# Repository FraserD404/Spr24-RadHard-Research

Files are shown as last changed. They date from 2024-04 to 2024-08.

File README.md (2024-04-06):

# Spr24 RadHard Research

## Overview:
EEPROM Control Code for Research

This code initializes EEPROMs on a PCB in select banks and then continuously dumps the data to see if there has been a bit flip.
This code is designed to run on a Raspberry Pi 4 with wiringPi library on a 1 MHz I2C bus.

## Known Issues:
- This is not memory safe as there is no code to free the alloc'd data structures. Only ~24 MB of garbage, however. I plan on fixing this soon.
- This code is prone to segmentation faults if any of the pins are disconnected. I don't know the fix for this.
- A full array dump takes approximately 2 minutes if the 512k dump is done in one pass. This is a limitation of the I2C bus. 
- This code could probably be more efficient time & space complexity-wise. I'll probably optimize this at some point.
- There is no tracking individual bit flips. This would be a reasonably simple implementation but time limits me. I do plan on implementing this.

## Files
Control File: radpicode.c
Test Files: filewriting.c , maybe.c

To compile on a Raspberry Pi: **gcc -o rad radpicode.c -l wiringPi**

Memory Usage: ~25 MB allocated total for 16 EEPROMs

CSV Size: ~1.3 KB over 5 minutes

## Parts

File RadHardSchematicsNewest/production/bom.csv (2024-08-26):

Designator | Footprint | Quantity | Value | LCSC Part #
A2 | Arduino_UNO_R3 | 1 | Arduino_UNO_R3
R10, R11, R12, R13, R14, R15, R4, R5, R6, R9 | 0603 | 10 | 10k
U1, U2 | TSSOP-16_4.4x5mm_P0.65mm | 2 | 74CBTLV3257
U10, U9 | TSSOP-8_4.4x3mm_P0.65mm | 2 | CAT24C 512XHM
U11, U14 | SOIC-8_3.9x4.9mm_P1.27mm | 2 | AT24CS01-SSHM
U12, U15 | SOIC-8_3.9x4.9mm_P1.27mm | 2 | AT24CS32-SSHM
U13, U16 | SOIC-8_3.9x4.9mm_P1.27mm | 2 | CAT24C128 SSHM
U17, U20 | TSSOP-8_4.4x3mm_P0.65mm | 2 | AT24CS01-XHM
U18, U21 | TSSOP-8_4.4x3mm_P0.65mm | 2 | AT24CS32-XHM
U19, U22 | TSSOP-8_4.4x3mm_P0.65mm | 2 | CAT24C128 XHM
U3, U4 | SOIC-8_3.9x4.9mm_P1.27mm | 2 | AT24CS04-SSHM
U5, U6 | TSSOP-8_4.4x3mm_P0.65mm | 2 | AT24CS04-XHM
U7, U8 | SOIC-8_3.9x4.9mm_P1.27mm | 2 | CAT24C 512

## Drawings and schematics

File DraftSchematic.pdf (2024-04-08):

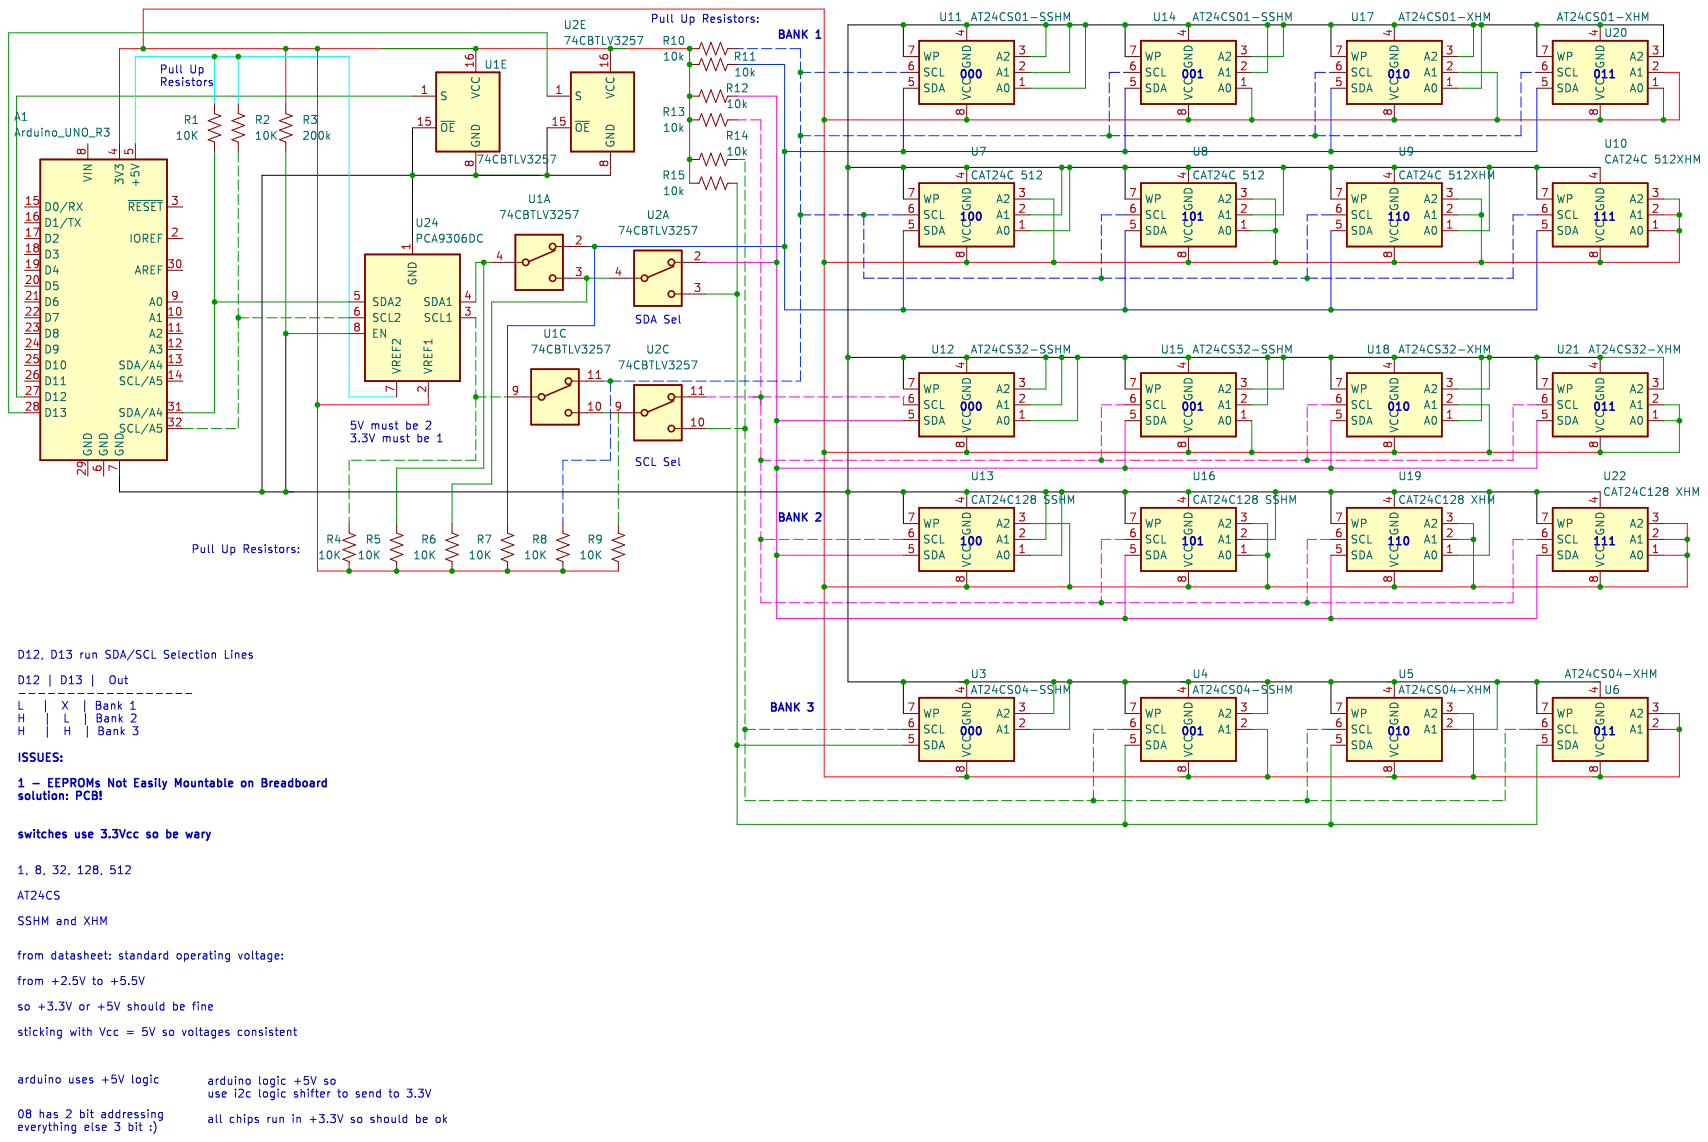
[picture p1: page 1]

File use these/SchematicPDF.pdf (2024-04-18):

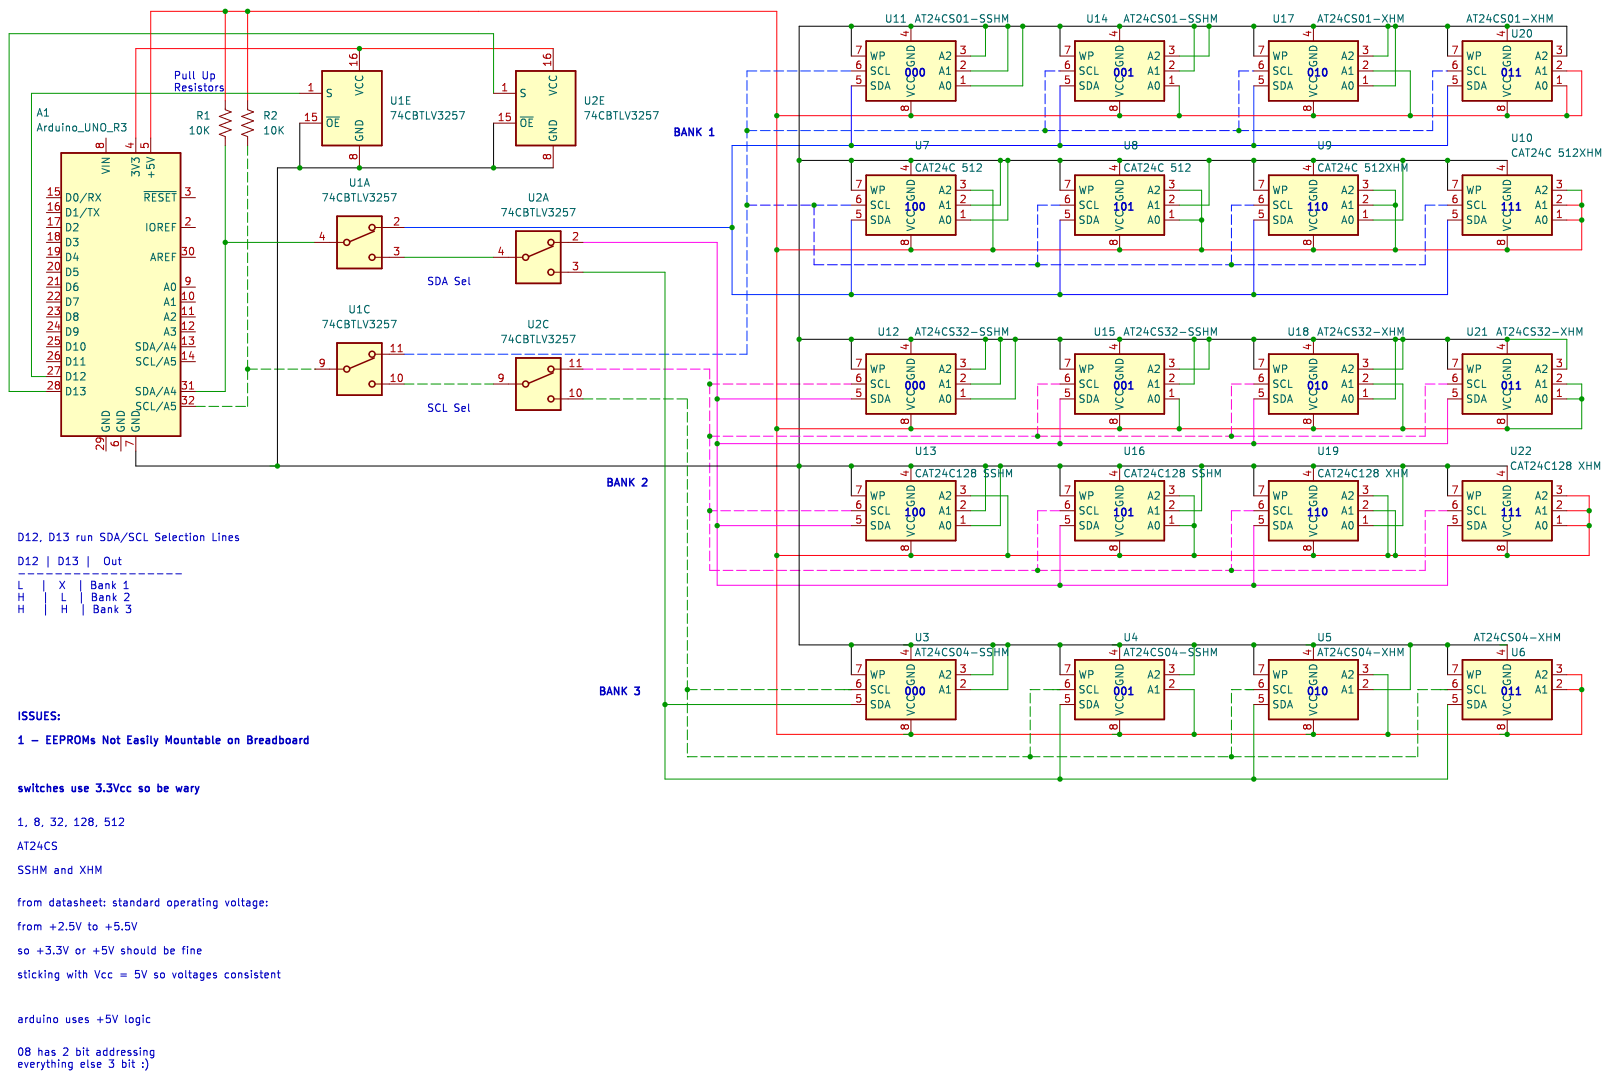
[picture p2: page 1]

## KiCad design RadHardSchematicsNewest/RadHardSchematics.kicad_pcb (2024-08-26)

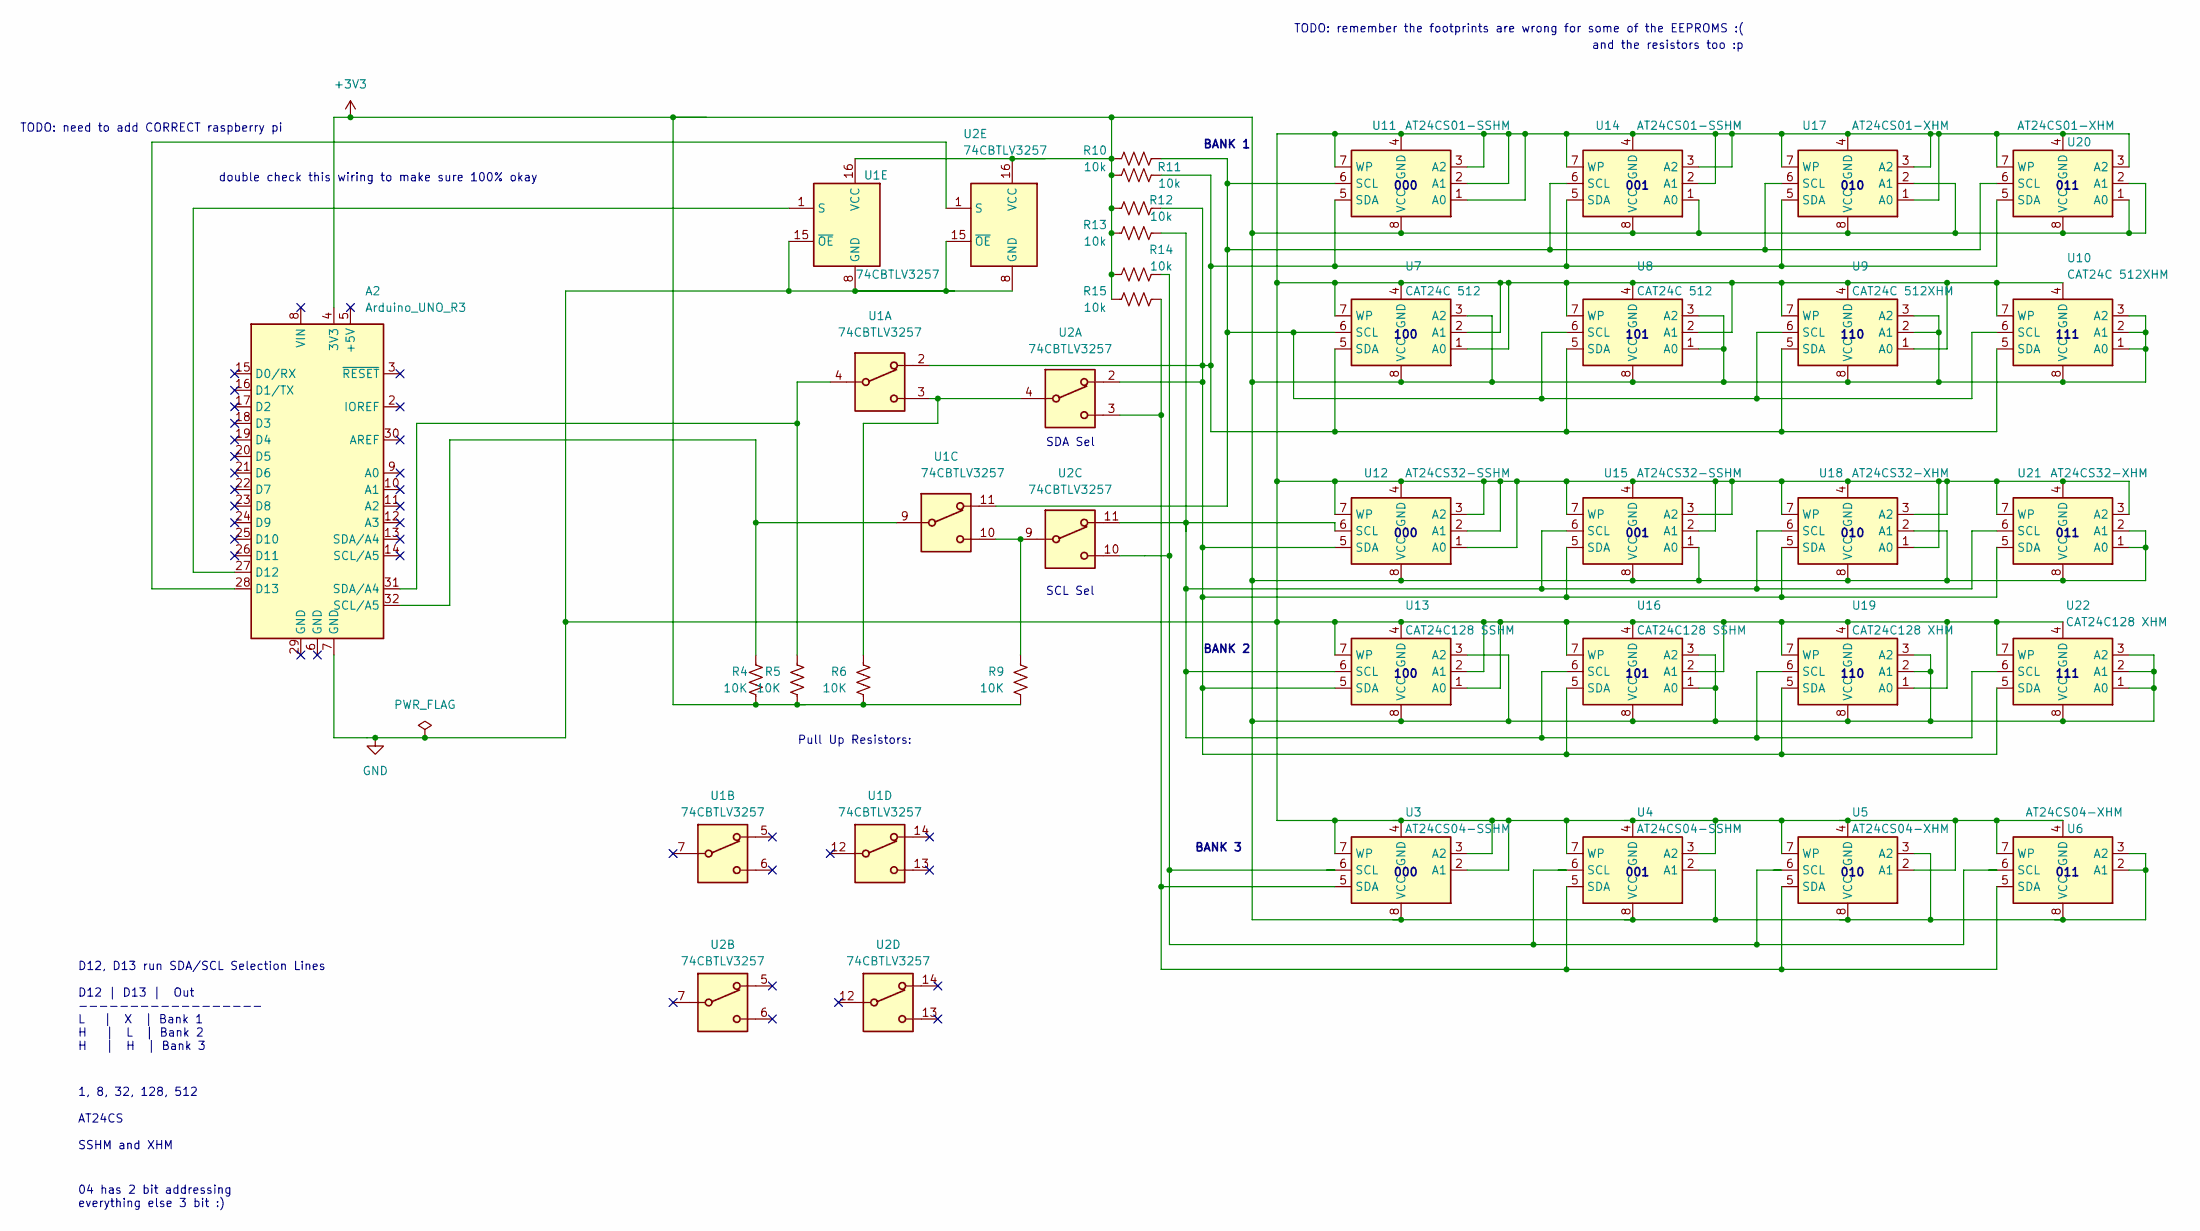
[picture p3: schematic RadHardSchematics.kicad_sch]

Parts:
A2: Arduino_UNO_R3
R4, R5, R6, R9: 10K; R_0603_1608Metric
R10, R11, R12, R13, R14, R15: 10k; R_0603_1608Metric
U1, U2: 74CBTLV3257; TSSOP-16_4.4x5mm_P0.65mm
U3, U4: AT24CS04-SSHM; SOIC-8_3.9x4.9mm_P1.27mm
U5, U6: AT24CS04-XHM; TSSOP-8_4.4x3mm_P0.65mm
U7, U8: CAT24C 512; SOIC-8_3.9x4.9mm_P1.27mm
U9, U10: CAT24C 512XHM; TSSOP-8_4.4x3mm_P0.65mm
U11, U14: AT24CS01-SSHM; SOIC-8_3.9x4.9mm_P1.27mm
U12, U15: AT24CS32-SSHM; SOIC-8_3.9x4.9mm_P1.27mm
U13, U16: CAT24C128 SSHM; SOIC-8_3.9x4.9mm_P1.27mm
U17, U20: AT24CS01-XHM; TSSOP-8_4.4x3mm_P0.65mm
U18, U21: AT24CS32-XHM; TSSOP-8_4.4x3mm_P0.65mm
U19, U22: CAT24C128 XHM; TSSOP-8_4.4x3mm_P0.65mm

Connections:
+3V3: A2.4 (3V3), R4.1, R5.1, R6.1, R9.1, R10.1, R11.1, R12.1, R13.1, R14.1, R15.1, U1.16 (VCC), U2.16 (VCC), U3.8 (VCC), U4.2 (A1), U4.8 (VCC), U5.3 (A2), U5.8 (VCC), U6.2 (A1), U6.3 (A2), U6.8 (VCC), U7.3 (A2), U7.8 (VCC), U8.1 (A0), U8.3 (A2), U8.8 (VCC), U9.2 (A1), U9.3 (A2), U9.8 (VCC), U10.1 (A0), U10.2 (A1), U10.3 (A2), U10.8 (VCC), U11.8 (VCC), U12.8 (VCC), U13.3 (A2), U13.8 (VCC), U14.1 (A0), U14.8 (VCC), U15.1 (A0), U15.8 (VCC), U16.1 (A0), U16.3 (A2), U16.8 (VCC), U17.2 (A1), U17.8 (VCC), U18.2 (A1), U18.8 (VCC), U19.2 (A1), U19.3 (A2), U19.8 (VCC), U20.1 (A0), U20.2 (A1), U20.8 (VCC), U21.1 (A0), U21.2 (A1), U21.8 (VCC), U22.1 (A0), U22.2 (A1), U22.3 (A2), U22.8 (VCC)
GND: A2.7 (GND), U1.8 (GND), U1.15 (~OE), U2.8 (GND), U2.15 (~OE), U3.2 (A1), U3.3 (A2), U3.4 (GND), U3.7 (WP), U4.3 (A2), U4.4 (GND), U4.7 (WP), U5.2 (A1), U5.4 (GND), U5.7 (WP), U6.4 (GND), U6.7 (WP), U7.1 (A0), U7.2 (A1), U7.4 (GND), U7.7 (WP), U8.2 (A1), U8.4 (GND), U8.7 (WP), U9.1 (A0), U9.4 (GND), U9.7 (WP), U10.4 (GND), U10.7 (WP), U11.1 (A0), U11.2 (A1), U11.3 (A2), U11.4 (GND), U11.7 (WP), U12.1 (A0), U12.2 (A1), U12.3 (A2), U12.4 (GND), U12.7 (WP), U13.1 (A0), U13.2 (A1), U13.4 (GND), U13.7 (WP), U14.2 (A1), U14.3 (A2), U14.4 (GND), U14.7 (WP), U15.2 (A1), U15.3 (A2), U15.4 (GND), U15.7 (WP), U16.2 (A1), U16.4 (GND), U16.7 (WP), U17.1 (A0), U17.3 (A2), U17.4 (GND), U17.7 (WP), U18.1 (A0), U18.3 (A2), U18.4 (GND), U18.7 (WP), U19.1 (A0), U19.4 (GND), U19.7 (WP), U20.3 (A2), U20.4 (GND), U20.7 (WP), U21.3 (A2), U21.4 (GND), U21.7 (WP), U22.4 (GND), U22.7 (WP)
unnamed: A2.27 (D12), U1.1 (S)
unnamed: A2.28 (D13), U2.1 (S)
unnamed: A2.32 (SCL/A5), R4.2, U1.9
unnamed: A2.31 (SDA/A4), R5.2, U1.4
unnamed: R6.2, U1.3, U2.4
unnamed: R9.2, U1.10, U2.9
unnamed: R14.2, U2.10, U3.6 (SCL), U4.6 (SCL), U5.6 (SCL), U6.6 (SCL)
unnamed: R15.2, U2.3, U3.5 (SDA), U4.5 (SDA), U5.5 (SDA), U6.5 (SDA)
unnamed: R10.2, U1.11, U7.6 (SCL), U8.6 (SCL), U9.6 (SCL), U10.6 (SCL), U11.6 (SCL), U14.6 (SCL), U17.6 (SCL), U20.6 (SCL)
unnamed: R11.2, R12.2, U1.2, U2.2, U7.5 (SDA), U8.5 (SDA), U9.5 (SDA), U10.5 (SDA), U11.5 (SDA), U12.5 (SDA), U13.5 (SDA), U14.5 (SDA), U15.5 (SDA), U16.5 (SDA), U17.5 (SDA), U18.5 (SDA), U19.5 (SDA), U20.5 (SDA), U21.5 (SDA), U22.5 (SDA)
unnamed: R13.2, U2.11, U12.6 (SCL), U13.6 (SCL), U15.6 (SCL), U16.6 (SCL), U18.6 (SCL), U19.6 (SCL), U21.6 (SCL), U22.6 (SCL)

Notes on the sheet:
SCL Sel
BANK 2
011
010
double check this wiring to make sure 100% okay
D12, D13 run SDA/SCL Selection Lines D12 | D13 | Out ------------------ L | X | Bank 1 H | L | Bank 2 H | H | Bank 3
111
001
110
Pull Up Resistors:
101
1, 8, 32, 128, 512 AT24CS SSHM and XHM
TODO: need to add CORRECT raspberry pi
04 has 2 bit addressing everything else 3 bit :)
100
BANK 1
000
TODO: remember the footprints are wrong for some of the EEPROMS :(
SDA Sel
and the resistors too :p
BANK 3

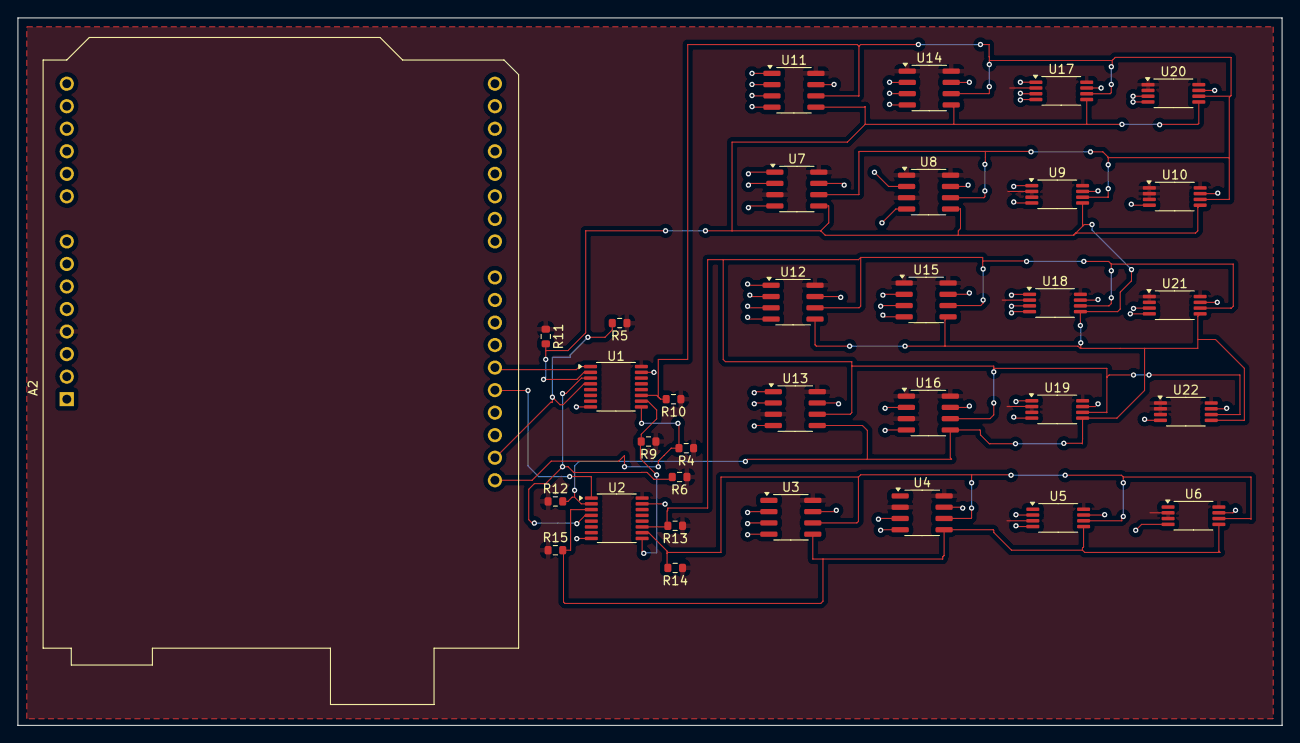
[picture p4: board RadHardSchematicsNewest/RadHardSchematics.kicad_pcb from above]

Board: 2 copper layers, 142.5 x 79.8 mm, 33 parts (0 on the bottom side), 13 nets.

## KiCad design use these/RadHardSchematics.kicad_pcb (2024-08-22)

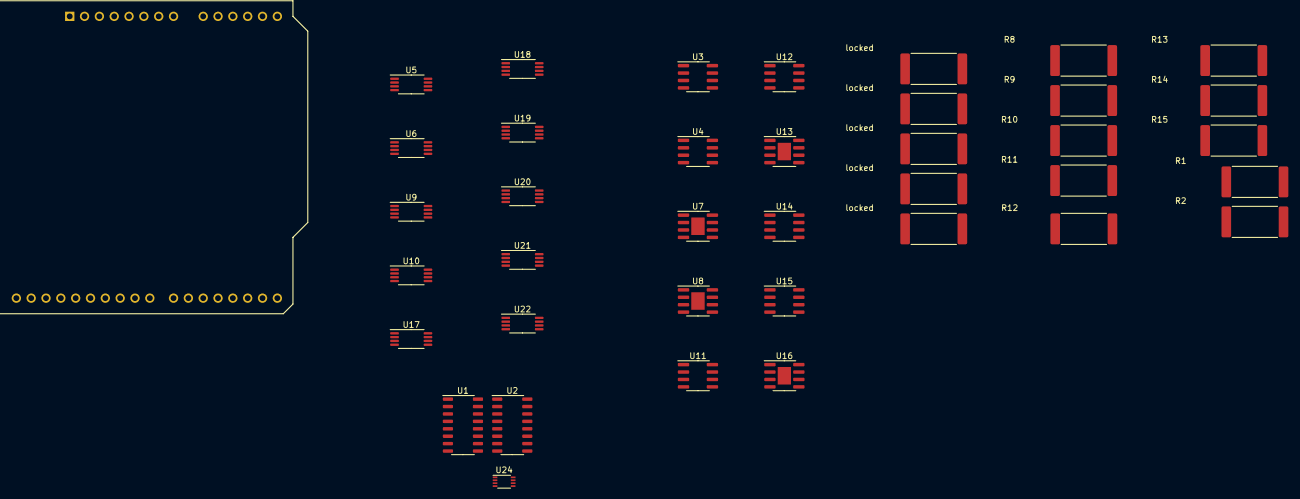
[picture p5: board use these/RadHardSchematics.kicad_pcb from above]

Board: 2 copper layers, 39 parts (0 on the bottom side), 16 nets, no tracks yet.

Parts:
A1: Arduino_UNO_R3
R1, R2, R8, R9: 10K; R_4020_10251Metric_Pad1.65x5.30mm_HandSolder
R10, R11, R12, R13, R14, R15: 10k; R_4020_10251Metric_Pad1.65x5.30mm_HandSolder
U1, U2: 74CBTLV3257; SO-16_3.9x9.9mm_P1.27mm
U3, U4: AT24CS04-SSHM; SOIC-8_3.9x4.9mm_P1.27mm
U5, U6: AT24CS04-XHM; TSSOP-8_4.4x3mm_P0.65mm
U7, U8: CAT24C 512; SOIC-8-1EP_3.9x4.9mm_P1.27mm_EP2.29x3mm
U9, U10: CAT24C 512XHM; TSSOP-8_4.4x3mm_P0.65mm
U11, U14: AT24CS01-SSHM; SOIC-8_3.9x4.9mm_P1.27mm
U12, U15: AT24CS32-SSHM; SOIC-8_3.9x4.9mm_P1.27mm
U13, U16: CAT24C128 SSHM; SOIC-8-1EP_3.9x4.9mm_P1.27mm_EP2.29x3mm
U17, U20: AT24CS01-XHM; TSSOP-8_4.4x3mm_P0.65mm
U18, U21: AT24CS32-XHM; TSSOP-8_4.4x3mm_P0.65mm
U19, U22: CAT24C128 XHM; TSSOP-8_4.4x3mm_P0.65mm
U24: PCA9306DC; VSSOP-8_2.3x2mm_P0.5mm
locked: 10K; R_4020_10251Metric_Pad1.65x5.30mm_HandSolder
locked#2, locked#4, locked#5: 10K; R_4020_10251Metric_Pad1.65x5.30mm_HandSolder
locked#3: 200k; R_4020_10251Metric_Pad1.65x5.30mm_HandSolder

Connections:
unnamed: A1.4 (3V3), R1.2, R2.1, R8.1, R9.1, R10.1, R11.1, R12.1, R13.1, R14.1, R15.1, U1.16 (VCC), U2.16 (VCC), U3.8 (VCC), U4.2 (A1), U4.8 (VCC), U5.3 (A2), U5.8 (VCC), U6.2 (A1), U6.3 (A2), U6.8 (VCC), U7.3 (A2), U7.8 (VCC), U8.1 (A0), U8.3 (A2), U8.8 (VCC), U9.2 (A1), U9.3 (A2), U9.8 (VCC), U10.1 (A0), U10.2 (A1), U10.3 (A2), U10.8 (VCC), U11.8 (VCC), U12.8 (VCC), U13.3 (A2), U13.8 (VCC), U14.1 (A0), U14.8 (VCC), U15.1 (A0), U15.8 (VCC), U16.1 (A0), U16.3 (A2), U16.8 (VCC), U17.2 (A1), U17.8 (VCC), U18.2 (A1), U18.8 (VCC), U19.2 (A1), U19.3 (A2), U19.8 (VCC), U20.1 (A0), U20.2 (A1), U20.8 (VCC), U21.1 (A0), U21.2 (A1), U21.8 (VCC), U22.1 (A0), U22.2 (A1), U22.3 (A2), U22.8 (VCC), U24.2 (VREF1), locked.1, locked#2.1, locked#3.1, locked#4.1, locked#5.1
unnamed: A1.5 (+5V), U24.7 (VREF2)
unnamed: A1.27 (D12), U1.1 (S)
unnamed: A1.28 (D13), U2.1 (S)
unnamed: U1.3, U2.4, locked.2
unnamed: R14.2, U2.10, U3.6 (SCL), U4.6 (SCL), U5.6 (SCL), U6.6 (SCL)
unnamed: R15.2, U2.3, U3.5 (SDA), U4.5 (SDA), U5.5 (SDA), U6.5 (SDA)
unnamed: A1.7 (GND), U1.8 (GND), U1.15 (~OE), U2.8 (GND), U2.15 (~OE), U3.2 (A1), U3.3 (A2), U3.4 (GND), U3.7 (WP), U4.3 (A2), U4.4 (GND), U4.7 (WP), U5.2 (A1), U5.4 (GND), U5.7 (WP), U6.4 (GND), U6.7 (WP), U7.1 (A0), U7.2 (A1), U7.4 (GND), U7.7 (WP), U8.2 (A1), U8.4 (GND), U8.7 (WP), U9.1 (A0), U9.4 (GND), U9.7 (WP), U10.4 (GND), U10.7 (WP), U11.1 (A0), U11.2 (A1), U11.3 (A2), U11.4 (GND), U11.7 (WP), U12.1 (A0), U12.2 (A1), U12.3 (A2), U12.4 (GND), U12.7 (WP), U13.1 (A0), U13.2 (A1), U13.4 (GND), U13.7 (WP), U14.2 (A1), U14.3 (A2), U14.4 (GND), U14.7 (WP), U15.2 (A1), U15.3 (A2), U15.4 (GND), U15.7 (WP), U16.2 (A1), U16.4 (GND), U16.7 (WP), U17.1 (A0), U17.3 (A2), U17.4 (GND), U17.7 (WP), U18.1 (A0), U18.3 (A2), U18.4 (GND), U18.7 (WP), U19.1 (A0), U19.4 (GND), U19.7 (WP), U20.3 (A2), U20.4 (GND), U20.7 (WP), U21.3 (A2), U21.4 (GND), U21.7 (WP), U22.4 (GND), U22.7 (WP), U24.1 (GND), U24.8 (EN), locked#3.2
unnamed: R8.2, R10.2, U1.10, U1.11, U2.9, U7.6 (SCL), U8.6 (SCL), U9.6 (SCL), U10.6 (SCL), U11.6 (SCL), U14.6 (SCL), U17.6 (SCL), U20.6 (SCL)
unnamed: R11.2, U1.2, U7.5 (SDA), U8.5 (SDA), U9.5 (SDA), U10.5 (SDA), U11.5 (SDA), U14.5 (SDA), U17.5 (SDA), U20.5 (SDA), locked#5.2
unnamed: R13.2, U2.11, U12.6 (SCL), U13.6 (SCL), U15.6 (SCL), U16.6 (SCL), U18.6 (SCL), U19.6 (SCL), U21.6 (SCL), U22.6 (SCL)
unnamed: R12.2, U2.2, U12.5 (SDA), U13.5 (SDA), U15.5 (SDA), U16.5 (SDA), U18.5 (SDA), U19.5 (SDA), U21.5 (SDA), U22.5 (SDA)
unnamed: U1.9, U24.3 (SCL1), locked#4.2
unnamed: A1.32 (SCL/A5), R2.2, U24.6 (SCL2)
unnamed: U1.4, U24.4 (SDA1), locked#2.2
unnamed: A1.31 (SDA/A4), R1.1, U24.5 (SDA2)

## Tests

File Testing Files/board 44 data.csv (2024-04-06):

Elapsed Time | Bank | EEPROM | Failures
0 | 0 | 0 | 4000
0 | 0 | 1 | 4000
0 | 0 | 2 | 4000
0 | 0 | 3 | 4000
0 | 0 | 4 | 512000
0 | 0 | 5 | 512000
0 | 0 | 6 | 512000
0 | 0 | 7 | 512000
0 | 1 | 0 | 32000
0 | 1 | 1 | 32000
0 | 1 | 2 | 32000
0 | 1 | 3 | 32000
0 | 1 | 4 | 128000
0 | 1 | 5 | 128000
0 | 1 | 6 | 128000
0 | 1 | 7 | 128000

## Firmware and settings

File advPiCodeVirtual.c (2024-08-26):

/*

    Updated & Better C Code for EEPROM Control for Research
	This includes advanced functionality:
	- Ability to count 1->0 and 0->1 bit flips
	- Ability to reinitialize any failed bits to good state
	- Ability to choose checkerboarding (FF00FF00) or uniform (all 00 or all FF) 

    August 21, 2024
    Author: Fraser Dougall 
	Email: fdougall@purdue.edu


	THIS IS THE CODE THAT WILL BE USED TO TEST THINGS VIRTUALLY
	NOT THE ACTUAL 

*/

// Libraries
#include <stdio.h>
#include <stdint.h>
#include <unistd.h>

//#include <wiringPi.h>
//#include <wiringPiI2C.h>

#include <time.h>
#include <stdbool.h>
#include <stdlib.h>

// Selector Pins
#define BANK_SELECT_1 0
#define BANK_SELECT_2 1

// EEPROM Banking Information
#define EEPROM_ADDRESS 0x50 // base EEPROM I2C address
#define NUM_BANKS 2
#define EEPROMS_PER_BANK 8
#define MAX_EEPROM_SIZE 512000 // maximum size we have

// How long to run the test - seconds
// default is 30 min -> 1800 seconds
#define RUNNING_TIME_SEC 1

// - - - - - - - - - - - - - - - - - - - - - - - - - - - - - - - - - - - - - - - - - -
typedef struct {
	int size;             // size in bytes of eeprom
	size_t failures;      // how many times has this EEPROM experienced a flip
	int i2cAddr;          // where on the i2c bus is it
	uint8_t* priorState;  // prior state of the EEPROM
	size_t oneToZeroFlips;// number of 1->0 bit flips
	size_t zeroToOneFlips;// number of 0->1 bit flips
	size_t hardFaultBits; // number of hardfaulting bits
} EEPROM; 

typedef struct {
	EEPROM* all;
} allEEPROMs; 

// - - - - - - - - - - - - - - - - - - - - - - - - - - - - - - - - - - - - - - - - - -

int totalEEPROMs = NUM_BANKS * EEPROMS_PER_BANK; 

// - - - - - - - - - - - - - - - - - - - - - - - - - - - - - - - - - - - - - - - - - -

// Return how many bytes are stored in a given bank,EEPROM combo
int getEEPROMSize(int bank, int num) {
	int sizeKB;

	switch(bank){
		case 0: 
			if(num >= 0 && num <= 3) { 
				sizeKB = 1;
			} else {
				sizeKB = 512; 
			}

			break;
		case 1: 
			if(num >= 0 && num <= 3) { 
				sizeKB = 32;
			} else { 
				sizeKB = 128; 
			}

			break;
		case 2: 
			if(num >= 0 && num <= 3) { 
				sizeKB = 4;
			} else {
				sizeKB = -1; 
			} 

			break;
		default:
			return -1; 
			break;
	}

	// kilobytes -> bytes
	return 1000 * sizeKB; 
}

/*
   Initialize GPIO Pins
   */
/*
   void initGPIO() {
   wiringPiSetup();

   pinMode(BANK_SELECT_1, OUTPUT);
   pinMode(BANK_SELECT_2, OUTPUT);
   }
   */

/*
   Choose with bank of EEPROM we are looking at by changing which switch state we are at
   */
/*
   void selectBank(int bank) {
   switch (bank) {
   case 0:
   digitalWrite(BANK_SELECT_1, LOW);
   digitalWrite(BANK_SELECT_2, LOW);

   break;
   case 1:
   digitalWrite(BANK_SELECT_1, HIGH);
   digitalWrite(BANK_SELECT_2, LOW);

   break;
   case 2:
   digitalWrite(BANK_SELECT_1, HIGH);
   digitalWrite(BANK_SELECT_2, HIGH);

   break;
   default:
   printf("Invalid bank number\n");

   break;
   }
   }
   */

/* 
   Initialize all EEPROMs to have 0xFF in all memory locations
   */
void initEEPROMs(allEEPROMs* population) {
	// stores current eeprom
	EEPROM* current = NULL;

	for (int bank = 0; bank < NUM_BANKS; bank++) {
		//selectBank(bank);

		for (int eeprom = 0; eeprom < EEPROMS_PER_BANK; eeprom++) {
			// grab current EEPROM from array
			current = (population->all) + (bank * EEPROMS_PER_BANK + eeprom); // this access is safe

			// current->i2cAddr = wiringPiI2CSetup(EEPROM_ADDRESS + eeprom);
			current->i2cAddr = 0xAF;

			// make sure EEPROM exists before accessing
			if (current->i2cAddr < 0) {
				printf("Failed to initialize EEPROM %d in bank %d\n", eeprom, bank);

				current->failures = -1; // this will underflow
			} else {
				current->size = getEEPROMSize(bank, eeprom);
				bool init = true;

				// Linearly initialize all locations in EEPROM ; wish this was faster but impossible for better than O(n)
				for (int num = 0; num < current->size; num++) {
					/*
					   if (wiringPiI2CWrite(current->i2cAddr, 0xFF) == -1) {
					   printf("Failed to write to EEPROM %d in bank %d\n", eeprom, bank);
					   init = false;

					   break;
					   } 		
					*/
				}

				if(init) {
					// malloc our saved addresses array
					current->priorState = calloc(current->size, sizeof(current->priorState));

					printf("Initialized EEPROM %d in bank %d\n", eeprom, bank);
				}

				close(current->i2cAddr);
			}
		}
	}
}


// remove this when testing on physical hardware
int correctValue = 0x0F;

void logger(time_t startTime, int greedy, int boardNum, FILE* csv_file, allEEPROMs* population) {
	time_t currTime = 0;
	int elapsedTime = 0; 
	int eepromSize = 0; 

	EEPROM* current = NULL;

	// Go through all EEPROMs and banks 
	for (int bank = 0; bank < NUM_BANKS; bank++) {
		//selectBank(bank); 

		for (int eeprom = 0; eeprom < EEPROMS_PER_BANK; eeprom++) {
			// Get current EEPROM from total population
			current = (population->all) + (bank * EEPROMS_PER_BANK + eeprom);
			// current->i2cAddr = wiringPiI2CSetup(EEPROM_ADDRESS + eeprom); 

			// make sure our EEPROM actually exists lol 
			if(current->i2cAddr >= 0) {
				for (int byte = 0; byte < current->size; byte++) {     
					//int data = wiringPiI2CRead(current->i2cAddr);

					// IN THIS CONTEXT correctValue == data so should be drop in replacement
					if(correctValue != (current->priorState)[byte] && correctValue > 0){
						current->failures = current->failures + 1; 

						uint8_t theByte = correctValue; 
						
						for(uint8_t i = 0; i<8; i++){
							// extract the bit we are looking at
							uint8_t currBit = (theByte & (1 << i)) >> i; 
							uint8_t priorBit= ((current->priorState)[byte] & (1 << i)) >> i; 

							// looks at 1->0 transitions 
							if(priorBit == 1 && currBit == 0){
								current->oneToZeroFlips += 1; 
							}

							// looks at 0->1 transitions
							if(priorBit == 0 && currBit == 1){
								current->zeroToOneFlips += 1; 
							}
						}
						
						// implement byte fixing here?

						// update our prior state
//						(current->priorState)[byte] = (uint8_t) correctValue; 
					} 
				}
				// get current time and calculate how long since we've started
				currTime = time(NULL); 
				elapsedTime = difftime(currTime, startTime); 

				// Log to CSV file 
				fprintf(csv_file, "%d, %d, %d, %d\n", elapsedTime, bank, eeprom, current->failures);

				close(current->i2cAddr); 
			} else {
				current->failures = -1337; // since it doesn't exist 
			}
		}
	}

	if(correctValue == 0x0F){correctValue = 0xAB;}
	else{correctValue = 0x0F;}

}


int main() {
	//    initGPIO();

	// illusion of choice ^-^ 

	printf("Board number: ");
	int num; 
	scanf("%d", &num); // todo: maybe do some error handling here?

	time_t ctime = time(NULL); 

	char filename[50];

	sprintf(filename, "board %d data.csv", num); // this is susceptible to buffer overflow if num is exceptionally large
	FILE *csv_file = fopen(filename, "a");

	if (csv_file == NULL) {
		printf("Failed to open CSV file\n");
		return -1;
	}

	fprintf(csv_file, "Elapsed Time, Bank, EEPROM, Failures\n");
	fclose(csv_file);
	fopen(filename, "a");

	// malloc our entire EEPROM handler
	allEEPROMs* population = (allEEPROMs*) malloc(sizeof(*population));

	// malloc storage of all our eeprom structs
	population->all = (EEPROM*) calloc(totalEEPROMs, sizeof(EEPROM));

	// Initialize everything
	initEEPROMs(population);

	// reset
	ctime = time(NULL); 

	printf("it's logging time\n");

	// Continuously log data - no sleep needed since takes time to read EEPROMs
	//
	// TODO: more finegrained control over how long we're running? (run exactly for 30 seconds)
	// if so need to figure out what timers we have access to on Pi
	while ( (int)(difftime(time(NULL), ctime)) <= RUNNING_TIME_SEC ) {
		logger(ctime, 0, num, csv_file, population);
		fclose(csv_file); // update file & flush buffer
		fopen(filename, "a");
	}

	// Close & Free all allocated stuff
	fclose(csv_file);

	// I am Become Free, Destroyer of EEPROMS
	// TODO: need to verify we're actually freeing everything (no valgrind installed :( )
	for(int i = 0; i < totalEEPROMs; i++){
		EEPROM* curr = (population->all) + i;

		if(curr != NULL && curr->priorState != NULL){
			free(curr->priorState);
		}
	}

	free(population->all);
	free(population);

	printf("Completed and written to file.\n"); 

	return 0;
}

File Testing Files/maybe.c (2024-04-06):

/*

Test CSV Storage File

April 5, 2024
Author: Fraser Dougall 
Email: fdougall@purdue.edu

*/

// Libraries
#include <stdio.h>
#include <stdint.h>
#include <unistd.h>
#include <time.h>
#include <stdbool.h>
#include <stdlib.h>

// EEPROM Banking Information
#define EEPROM_ADDRESS 0x50 // base EEPROM I2C address
#define NUM_BANKS 2         // three exist physically but not working + redundant
#define EEPROMS_PER_BANK 8  // eep/bank
#define MAX_EEPROM_SIZE 512000 // maximum size we have

// How long to run the test - seconds
// default is 30 min -> 1800 seconds
#define RUNNING_TIME_SEC 2

// - - - - - - - - - - - - - - - - - - - - - - - - - - - - - - - - - - - - - - - - - -

//typedef struct {
  //  uint8_t* addresses;
//} eepromMemArray; 

typedef struct {
    int size;
    int failures; 
    int i2cAddr; 
    uint8_t* mems;
} EEPROM; 

typedef struct {
    EEPROM* all;
} allEEPROMs; 

// - - - - - - - - - - - - - - - - - - - - - - - - - - - - - - - - - - - - - - - - - -

// global variables :(
int totalEEPROMs = NUM_BANKS * EEPROMS_PER_BANK; 

// - - - - - - - - - - - - - - - - - - - - - - - - - - - - - - - - - - - - - - - - - -

// Return how many bytes are stored in a given bank,EEPROM combo
// this is a really stupid and inefficient piece of code 
// figure out a better way
int getEEPROMSize(int bank, int num) {
    int sizeKB;

    switch(bank){
        case 0: 
            if(num >= 0 && num <= 3) { 
                sizeKB = 4;
            } else {
                sizeKB = 512; 
            }

            break;
        case 1: 
            if(num >= 0 && num <= 3) { 
                sizeKB = 32;
            } else { 
                sizeKB = 128; 
            }

            break;
        case 2: 
            if(num >= 0 && num <= 3) { 
                sizeKB = 256;
            } else {
                sizeKB = 64; 
            } 

            break;
        default:
            return -1; 
            break;
    }

    // kilobytes -> bytes
    return 1000 * sizeKB; 
}

// pass into initialization function
void initEEPROMs(allEEPROMs* population) {
    // stores current eeprom
    EEPROM* current = (EEPROM*) malloc(sizeof(current)); 

    for (int bank = 0; bank < NUM_BANKS; bank++) {
       // selectBank(bank);

        for (int eeprom = 0; eeprom < EEPROMS_PER_BANK; eeprom++) {

            // grab current EEPROM from array
            current = &((population->all)[bank * EEPROMS_PER_BANK  + eeprom]);
           // current->i2cAddr = wiringPiI2CSetup(EEPROM_ADDRESS + eeprom);
            current->i2cAddr = 1; 
	    
            if (current->i2cAddr < 0) {
                printf("Failed to initialize EEPROM %d in bank %d\n", eeprom, bank);
            } else {
		        current->size = getEEPROMSize(bank, eeprom);
		        bool init = true;

                // Linearly initialize all locations in EEPROM ; wish this was faster but impossible for better than O(n)
                /*
                for (int num = 0; num < current->size; num++) {
                    if (wiringPiI2CWrite(current->i2cAddr, 0xFF) == -1) {
                        printf("Failed to write to EEPROM %d in bank %d\n", eeprom, bank);
                        init = false;

                        break;
                    } 		
                }
            */

                if(init) {
                    // malloc our saved addresses array
                    current->mems = calloc(current->size, sizeof(current->mems)); 
                    //(current->mems)->addresses = malloc(sizeof((current->mems)->addresses) * current->size);
		   current->failures = 0;
                    //for(int l = 0; l < current->size; l++) {
                      //  (current->mems)[l] = 0; 
                   // }
                    printf("Initialized EEPROM %d in bank %d\n", eeprom, bank);
                }

                //close(current->i2cAddr);
            }
        }
    }

    // free our temporary storage
//    free(current); 
}

void logger(time_t startTime, int greedy, int boardNum, FILE* csv_file, allEEPROMs* population) {
    time_t currTime = 0;
    int elapsedTime = 0; 
    int eepromSize = 0; 

    EEPROM* current = (EEPROM*) malloc(sizeof(current)); 

    // Go through all EEPROMs and banks 
    for (int bank = 0; bank < NUM_BANKS; bank++) {
        for (int eeprom = 0; eeprom < EEPROMS_PER_BANK; eeprom++) {
            // Get current EEPROM from total population
            current = &((population->all)[bank * EEPROMS_PER_BANK  + eeprom]);

            for (int byte = 0; byte < current->size; byte++) {     
                //uint8_t data = wiringPiI2CRead(eepromAddr);

                uint8_t data = 0xAF; 

                if(data != 0xFF){
                    // check to see if we've looked at this before
                    // yay O(1) access but rip space complexity :( 
                    if( ((current->mems)[byte] != 1)) {
                        current->failures =  current->failures + 1; 
                        (current->mems)[byte] = 1;
                    } // otherwise we do not want to double count failure
                }
            }
            // get current time and calculate how long since we've started
            currTime = time(NULL); 
            elapsedTime = difftime(currTime, startTime); 

            // Log to CSV file 
            fprintf(csv_file, "%d, %d, %d, %d\n", elapsedTime, bank, eeprom, current->failures);
        }
    }

   // free(current); 
}
/*
void logger(time_t startTime, int greedy, int boardNum, FILE* csv_file, int** eepromFailures) {
    time_t currTime = 0;
    int elapsedTime = 0; 
    int eepromSize = 0; 

    // Go through all EEPROMs and banks 
    for (int bank = 0; bank < NUM_BANKS; bank++) {
        for (int eeprom = 0; eeprom < EEPROMS_PER_BANK; eeprom++) {
            eepromSize = getEEPROMSize(bank, eeprom);

            for (int byte = 0; byte < eepromSize; byte++) {     
                // check if already seen

                while(potential != NULL) {
                    if(potential->byte == byte) {
                        seen = True; 
                        break;
                    }
                }
                eepromFailures[bank][eeprom] = eepromFailures[bank][eeprom] + 1; 
            }

            // get current time and calculate how long since we've started
            currTime = time(NULL); 
            elapsedTime = difftime(currTime, startTime); 

            // Log to CSV file 
            fprintf(csv_file, "%d, %d, %d, %d\n", elapsedTime, bank, eeprom, eepromFailures[bank][eeprom]);
            //printf("Elapsed Time %0.2f, Bank %d, EEPROM %d, Failures: %d\n", elapsedTime, bank, eeprom, eepromFailures[b * NUM_BANKS + e]);
        }
    }
}
*/
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

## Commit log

2024-04-05 File Writing Testing
    implemented csv writing, debugged
    [board 3 data.csv]
2024-04-06 Filewriting update
    base software should be okay
    [board 4 data.csv, board 5 data.csv, board 7 data.csv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]
2024-04-06 fixed bugs (i hope)
    please
    [board 4 data.csv]
2024-04-06 fixed memory issues
    for realises this time
    [maybe.c, radpicode.c]
2024-04-06 Functionally Final Code
    finally
    [board 99 data.csv]
2024-04-06 update runtime
    [board 420 data.csv]
2024-04-06 Update structure & readme
    yeah
    [board 3 data.csv, board 4 data.csv, board 420 data.csv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]
2024-04-08 Added extras for presentation
    [board 3 data.csv, board 5 data.csv, board 6 data.csv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]
2024-04-18 added schematics
    [RadHardSchematics.kicad_pcb, RadHardSchematics.kicad_sch, processed.xlsx]
2024-04-22 New PCB
    [JLCPCB.kicad_pcb, RadHardSchematics.kicad_pcb, RadHardSchematics.kicad_sch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]
2024-08-21 latest pcb push
    [RadHardSchematics.kicad_pcb, RadHardSchematics.kicad_sch, board 2 data.csv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]
2024-08-22 pushing actual schematics lol
    [RadHardSchematics.kicad_pcb, RadHardSchematics.kicad_sch, SchemIV.kicad_sch]
2024-08-22 Added New PCB
    [RadHardSchematics.kicad_pcb, RadHardSchematics.kicad_sch, bom.csv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]
2024-08-26 Changed Footprints for New PCB
    [RadHardSchematics.kicad_pcb, RadHardSchematics.kicad_sch, bom.csv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]
